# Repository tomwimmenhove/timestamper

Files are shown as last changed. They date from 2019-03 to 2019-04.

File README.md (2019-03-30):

# The Timestamper

This project lets you get get exact timestamps of 'events' (electric pulses on an input).

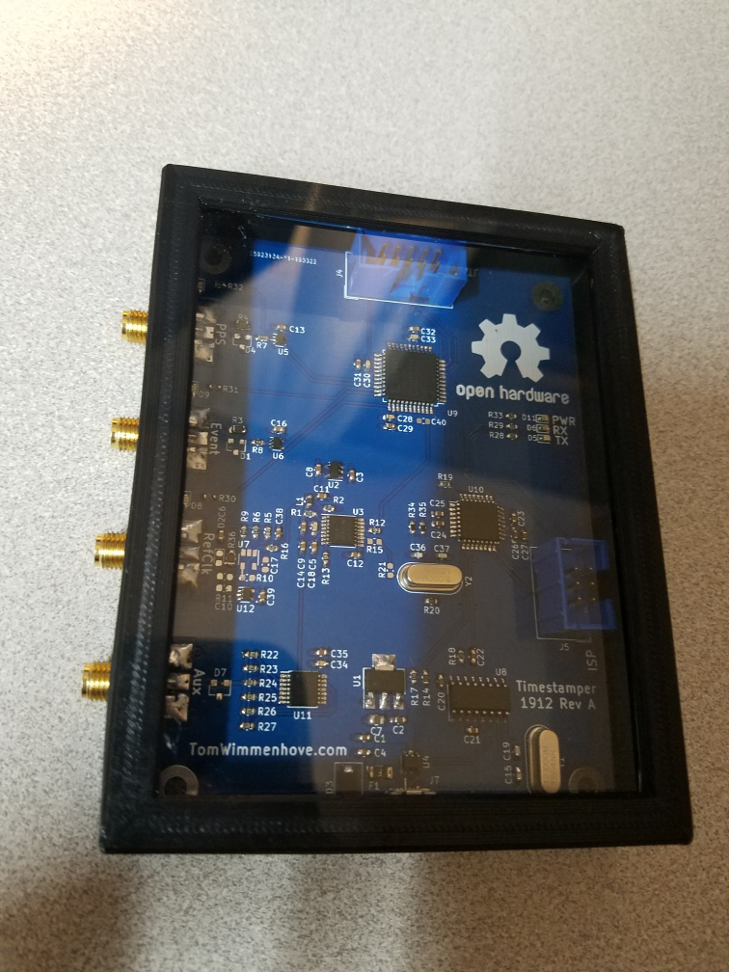
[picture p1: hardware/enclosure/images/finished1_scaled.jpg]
TimeStamper image


## Hardware
The hardware (schematic and PCB) are designed in KiCad 5, and can be found in the ./hardware/cpld/ directory. The 'heart'
of the design is a Xilinx XC9572XL CPLD. This CPLD implements a capture-counter which timestamps the arrival of events
with a resolution of 10ns. This CPLD is programmed in VHDL using Xilinx's ISE 14.7 (https://www.xilinx.com/support/download/index.html/content/xilinx/en/downloadNav/design-tools/v2012_4---14_7.html).

The VHDL project resides in the ./hardware/cpld/ directory. The XC9572XL can be programmed using the xc3sprog (http://xc3sprog.sourceforge.net/) utility.
Both the 'ft232h' (with a serial FT232H UART chip) and the 'sysfsgpio' (sysfsgpio on the Raspberry Pi) have been
successfully used to program the chip.

## Firmware
The firmware runs on an Atmel Atmega328p, which makes it compatible with the arduino. This way, using the default bootloader for,
for example, the Arduino pro mini 3.3v @8Mhz, we can easily program the firmware using avrdude. The firmware simply reads the
captured values from the CPLD and passes them on to a CH340G serial to USB UART. The firmware can be found in ./firmware/atmega328/

## Software
The software just outputs the values from the device onto stdout. See ./software/

# Theory of operation
The board is fed 3 signals:
 - A (very stable) 10MHz reference clock (I.E. from an OCXO or atomic rubidium reference)
 - A precise PPS signal, indicating the start of a UTC second. (I.E. from a GPS timing receiver)
 - An event signal that needs to be precisely timestamped.
 
 The 10Mhz is fed into a PLL (A Texas Instruments CDCE925), and multiplied to 100MHz, which is then fed to the CPLD.
 Inside the CPLD, this clocks a 27-bit counter. This counter is (synchronously) reset on the rising edge of the PPS
 signal. The event signal is sampled at every clock pulse, and when a rising-edge is detected, the current count is stored
 inside into a register and the capture counter is 'disarmed'. The CPLD then notifies the Atmega328P through an interrupt
 which, in turn, reads the value from the CPLD, places it in a buffer, and instructs the CPLD te re-arm the capture logic.
 The capture value is then simply sent out of the USB UART to the PC. We now have the fractional part of the timestamp on
 the PC. This can be combined with the current time on the PC to form a complete timestamp.
 NOTE: This assumes that the time on the PC that is reading the timestamps is well within a 500ms tolerance.
 
 # Links and other stuff
 See https://www.febo.com/pages/soekris/ for details on making an accurate NTP server.
 In addition, a Motorola m12+ GPS timing receiver together with a saw-tooth correction circuit is used to provide both a
 UTC time-source for the NTP server, as well as a PPS pulse for the Timestamper board.
 The Timestamper board also contains an 'auxiliary' output, which could be programmed to output a 33MHz clock that could
 be fed into the Soekris' motherboard to provide an even more accurate NTP time source (untested).

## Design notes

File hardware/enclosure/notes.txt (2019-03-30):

You might want to print the lid at a 99.5% scale.

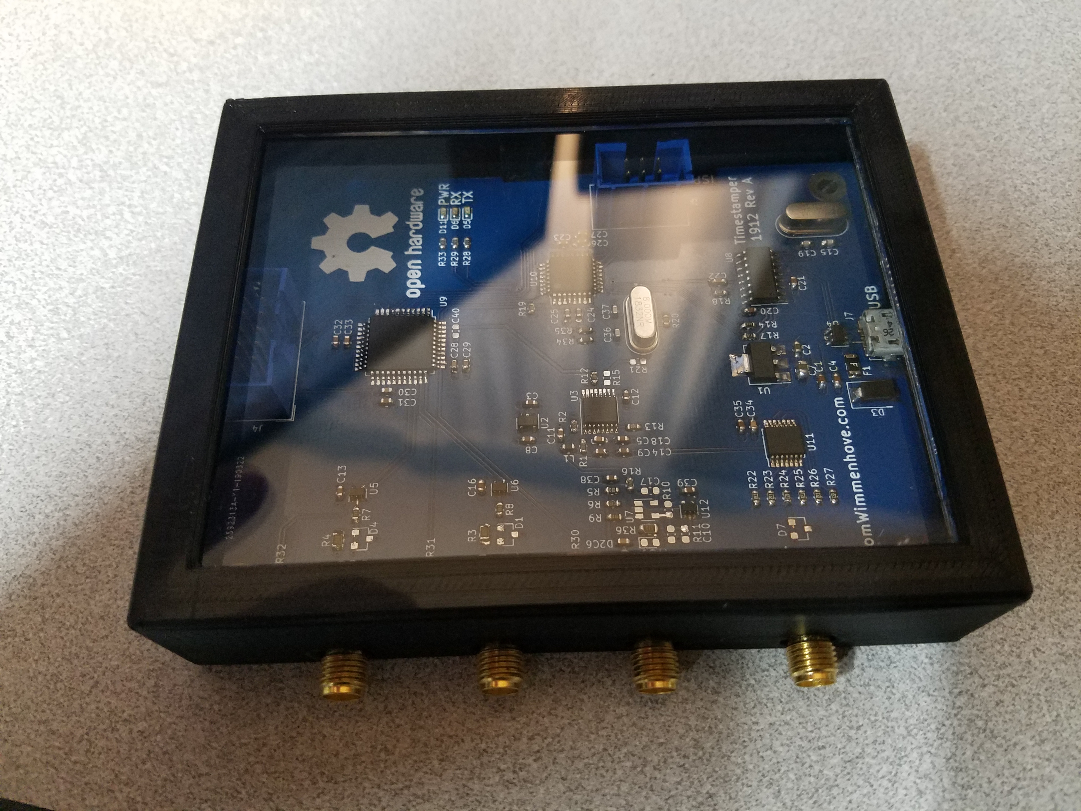
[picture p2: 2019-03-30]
hardware/enclosure/images/finished2.jpg

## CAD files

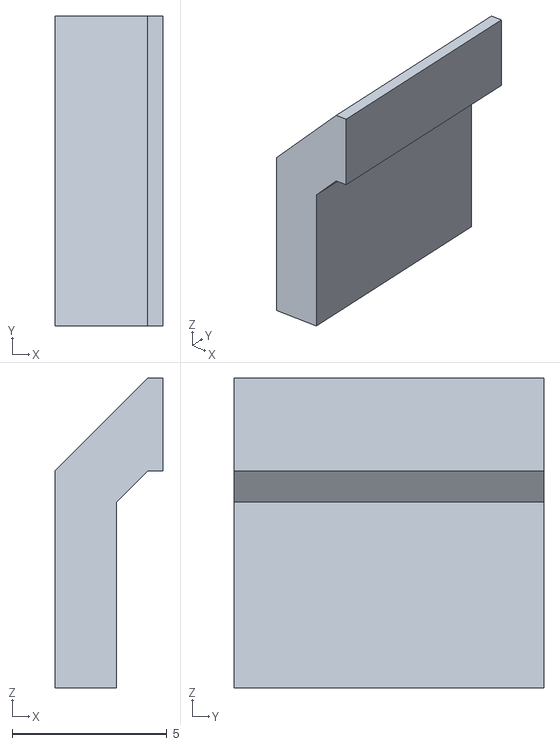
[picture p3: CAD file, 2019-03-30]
hardware/enclosure/pcb_clip.stl
3.50 x 10.0 x 10.0

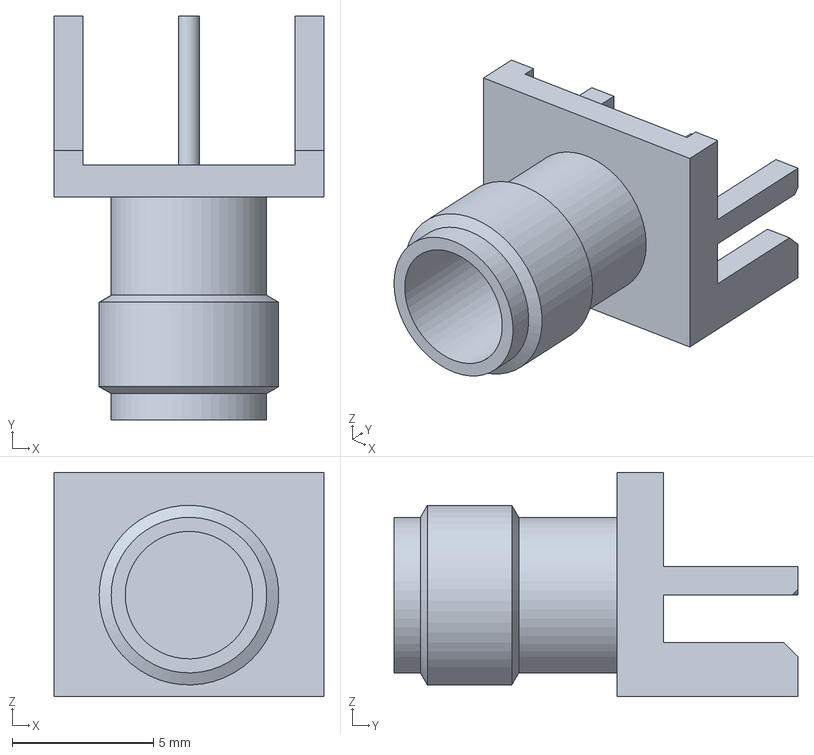
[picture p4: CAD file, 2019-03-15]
hardware/pcb/3dmodels/SMA_Board_Edge_Molex_732511150.step
9.53 x 14.3 x 7.93 mm

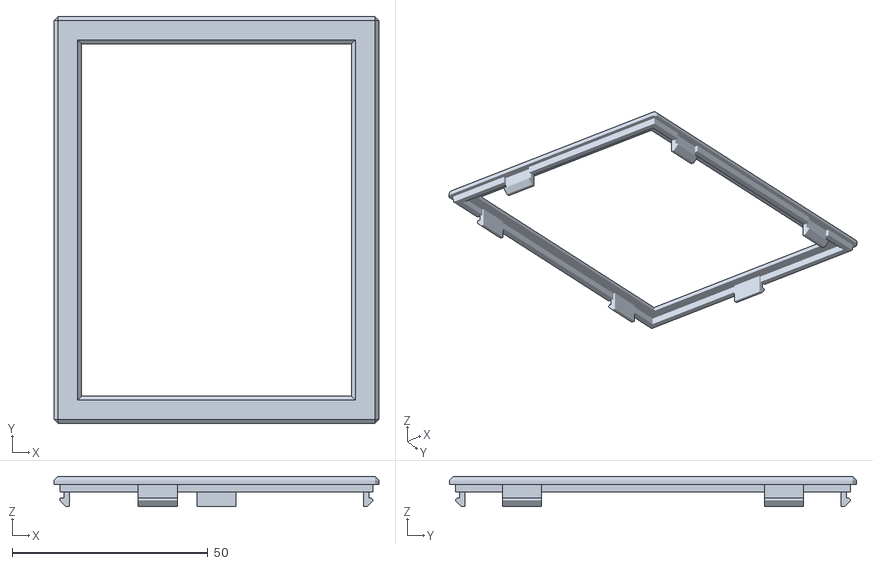
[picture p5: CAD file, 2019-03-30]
hardware/enclosure/lid.stl
83.0 x 104.0 x 7.70

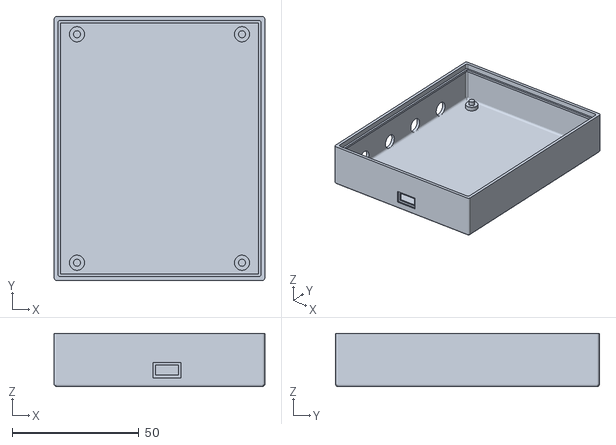
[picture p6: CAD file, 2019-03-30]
hardware/enclosure/bottom.stl
83.0 x 104.0 x 21.0

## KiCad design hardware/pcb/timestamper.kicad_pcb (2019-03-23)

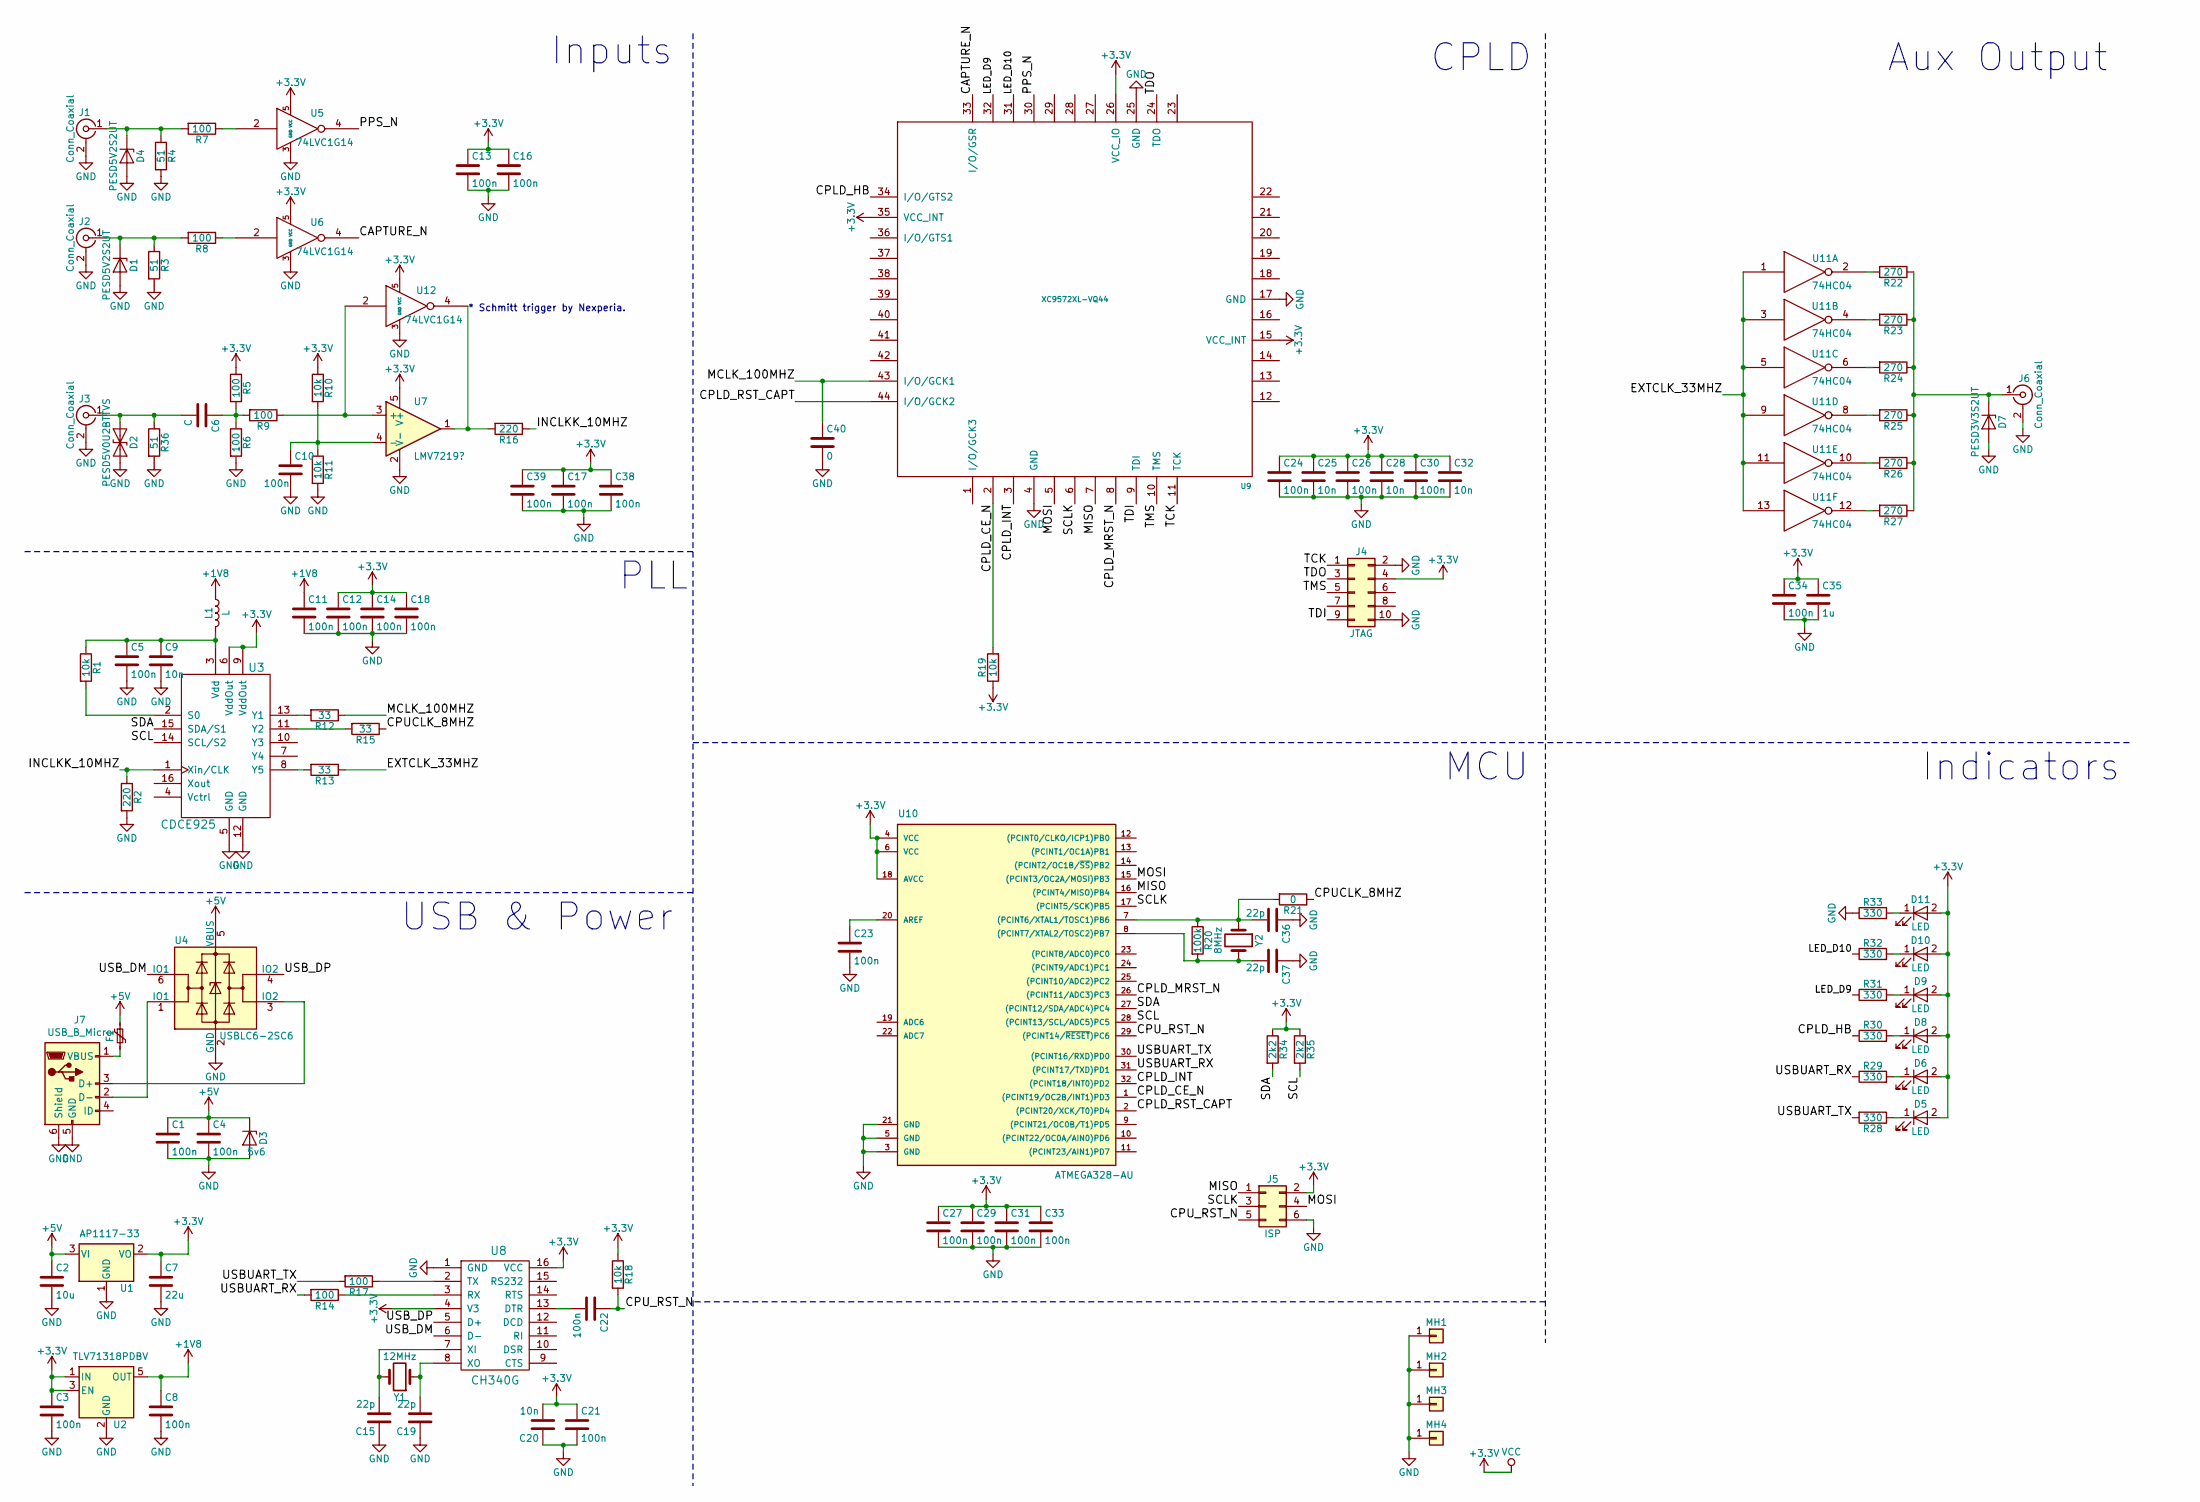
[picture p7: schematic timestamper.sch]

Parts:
C1, C3, C4, C5, C8, C10, C11, C12, C13, C14, C16, C17, C18, C21, C22, C23, C24, C26, C27, C29, C30, C31, C33, C34, C38, C39: 100n; C_0603_1608Metric
C2: 10u; C_0603_1608Metric
C6: C; C_0603_1608Metric
C7: 22u; C_0805_2012Metric
C9, C20, C25, C28, C32: 10n; C_0603_1608Metric
C15, C19, C36, C37: 22p; C_0603_1608Metric
C35: 1u; C_0603_1608Metric
C40: 0; C_0603_1608Metric
D1, D4: PESD5V2S2UT; D_SOT-23_NKA
D2: PESD5V0U2BTTVS; D_0603_1608Metric
D3: 5v6; D_SMB
D5, D6, D8, D9, D10, D11: LED; LED_0603_1608Metric
D7: PESD3V3S2UT; D_SOT-23_NKA
F1: Polyfuse_Small; R_1206_3216Metric
J1, J2, J3, J6: Conn_Coaxial; Molex_SMA_Jack_Edge_Mount
J4: JTAG; IDC-Header_2x05_P2.54mm_Vertical
J5: ISP; IDC-Header_2x03_P2.54mm_Vertical
J7: USB_B_Micro; USB_Micro-B_Molex_47346-0001
L1: L; L_0603_1608Metric
MH1, MH2, MH3, MH4: Conn_01x01; MountingHole_3.2mm_M3_Pad
R1, R10, R11, R18, R19: 10k; R_0603_1608Metric
R2, R16: 220; R_0603_1608Metric
R3, R4, R36: 51; R_0805_2012Metric
R5, R6, R7, R8, R9, R14, R17: 100; R_0603_1608Metric
R12, R13, R15: 33; R_0603_1608Metric
R20: 100k; R_0603_1608Metric
R21: 0; R_0603_1608Metric
R22, R23, R24, R25, R26, R27: 270; R_0603_1608Metric
R28, R29, R30, R31, R32, R33: 330; R_0603_1608Metric
R34, R35: 2k2; R_0603_1608Metric
U1: AP1117-33; SOT-223-3_TabPin2
U2: TLV71318PDBV; SOT-23-5
U3: CDCE925; TSSOP-16_4.4x5mm_P0.65mm
U4: USBLC6-2SC6; SOT-23-6
U5, U6, U12: 74LVC1G14; SOT-353_SC-70-5
U7: LMV7219?; SOT-23-5
U8: CH340G; SOIC-16_3.9x9.9mm_P1.27mm
U9: XC9572XL-VQ44; PQFP-44_10x10mm_P0.8mm
U10: ATMEGA328-AU; TQFP-32_7x7mm_P0.8mm
U11: 74HC04; TSSOP-14_4.4x5mm_P0.65mm
Y1: 12MHz; Crystal_HC49-4H_Vertical
Y2: 8MHz; Crystal_HC49-4H_Vertical

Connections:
+1V8: C8.1, C11.1, L1.1, U2.5 (OUT)
+3V3: C3.1, C7.1, C12.1, C13.1, C14.1, C16.1, C17.1, C18.1, C20.2, C21.1, C24.1, C25.1, C26.1, C27.1, C28.1, C29.1, C30.1, C31.1, C32.1, C33.1, C34.1, C35.1, C38.1, C39.1, D5.2 (A), D6.2 (A), D8.2 (A), D9.2 (A), D10.2 (A), D11.2 (A), J4.4, J5.2, R5.1, R10.1, R18.1, R19.1, R34.1, R35.1, U1.2 (VO), U2.1 (IN), U2.3 (EN), U3.6 (VddOut), U3.9 (VddOut), U5.5 (VCC), U6.5 (VCC), U7.5 (V+), U8.4 (V3), U8.16 (VCC), U9.15 (VCC_INT), U9.26 (VCC_IO), U9.35 (VCC_INT), U10.4 (VCC), U10.6 (VCC), U10.18 (AVCC), U11.14 (VCC), U12.5 (VCC)
+5V: C1.1, C2.1, C4.1, D3.1 (K), F1.1, U1.3 (VI), U4.5 (VBUS)
/CAPTURE_N: U6.4, U9.33 (I/O/GSR)
/CPLD_CE_N: R19.2, U9.2, U10.1 ((PCINT19/OC2B/INT1)PD3)
/CPLD_HB: R30.1, U9.34 (I/O/GTS2)
/CPLD_INT: U9.3, U10.32 ((PCINT18/INT0)PD2)
/CPLD_MRST_N: U9.8, U10.26 ((PCINT11/ADC3)PC3)
/CPLD_RST_CAPT: U9.44 (I/O/GCK2), U10.2 ((PCINT20/XCK/T0)PD4)
/CPUCLK_8MHZ: R15.1, R21.1
/CPU_RST_N: C22.1, J5.5, R18.2, U10.29 ((PCINT14/~RESET~)PC6)
/EXTCLK_33MHZ: R13.1, U11.1, U11.3, U11.5, U11.9, U11.11, U11.13
/INCLKK_10MHZ: R2.1, R16.1, U3.1 (Xin/CLK)
/LED_D9: R31.1, U9.32
/LED_D10: R32.1, U9.31
/MCLK_100MHZ: C40.1, R12.1, U9.43 (I/O/GCK1)
/MISO: J5.1, U9.7, U10.16 ((PCINT4/MISO)PB4)
/MOSI: J5.4, U9.5, U10.15 ((PCINT3/OC2A/MOSI)PB3)
/PPS_N: U5.4, U9.30
/SCL: R35.2, U3.14 (SCL/S2), U10.28 ((PCINT13/SCL/ADC5)PC5)
/SCLK: J5.3, U9.6, U10.17 ((PCINT5/SCK)PB5)
/SDA: R34.2, U3.15 (SDA/S1), U10.27 ((PCINT12/SDA/ADC4)PC4)
/TCK: J4.1, U9.11 (TCK)
/TDI: J4.9, U9.9 (TDI)
/TDO: J4.3, U9.24 (TDO)
/TMS: J4.5, U9.10 (TMS)
/USBUART_RX: R14.2, R29.1, U10.31 ((PCINT17/TXD)PD1)
/USBUART_TX: R17.2, R28.2, U10.30 ((PCINT16/RXD)PD0)
/USB_DM: U4.6 (IO1), U8.6 (D-)
/USB_DP: U4.4 (IO2), U8.5 (D+)
GND: C1.2, C2.2, C3.2, C4.2, C5.2, C7.2, C8.2, C9.2, C10.2, C11.2, C12.2, C13.2, C14.2, C15.1, C16.2, C17.2, C18.2, C19.1, C20.1, C21.2, C23.2, C24.2, C25.2, C26.2, C27.2, C28.2, C29.2, C30.2, C31.2, C32.2, C33.2, C34.2, C35.2, C36.1, C37.1, C38.2, C39.2, C40.2, D1.2 (A), D2.2 (A2), D3.2 (A), D4.2 (A), D7.2 (A), J1.2 (Ext), J2.2 (Ext), J3.2 (Ext), J4.2, J4.10, J5.6, J6.2 (Ext), J7.5 (GND), J7.6 (Shield), MH1.1, MH2.1, MH3.1, MH4.1, R2.2, R3.2, R4.2, R6.2, R11.2, R33.1, R36.2, U1.1 (GND), U2.2 (GND), U3.5 (GND), U3.12 (GND), U4.2 (GND), U5.3 (GND), U6.3 (GND), U7.2 (V-), U8.1 (GND), U9.4 (GND), U9.17 (GND), U9.25 (GND), U10.3 (GND), U10.5 (GND), U10.21 (GND), U11.7 (GND), U12.3 (GND)
unnamed: C5.1, C9.1, L1.2, R1.1, U3.3 (Vdd)
unnamed: C6.1, R5.2, R6.1, R9.2
unnamed: C6.2, D2.1 (A1), J3.1 (In), R36.1
unnamed: C10.1, R10.2, R11.1, U7.4 (-)
unnamed: C15.2, U8.7 (XI), Y1.2
unnamed: C19.2, U8.8 (XO), Y1.1
unnamed: C22.2, U8.13 (DTR)
unnamed: C23.1, U10.20 (AREF)
unnamed: C36.2, R20.1, R21.2, U10.7 ((PCINT6/XTAL1/TOSC1)PB6), Y2.1
unnamed: C37.2, R20.2, U10.8 ((PCINT7/XTAL2/TOSC2)PB7), Y2.2
unnamed: D1.1 (K), J2.1 (In), R3.1, R8.2
unnamed: D4.1 (K), J1.1 (In), R4.1, R7.2
unnamed: D5.1 (K), R28.1
unnamed: D6.1 (K), R29.2
unnamed: D7.1 (K), J6.1 (In), R22.1, R23.1, R24.1, R25.1, R26.1, R27.1
unnamed: D8.1 (K), R30.2
unnamed: D9.1 (K), R31.2
unnamed: D10.1 (K), R32.2
unnamed: D11.1 (K), R33.2
unnamed: F1.2, J7.1 (VBUS)
unnamed: J7.2 (D-), U4.1 (IO1)
unnamed: J7.3 (D+), U4.3 (IO2)
unnamed: R1.2, U3.2 (S0)
unnamed: R7.1, U5.2
unnamed: R8.1, U6.2
unnamed: R9.1, U7.3 (+), U12.2
unnamed: R12.2, U3.13 (Y1)
unnamed: R13.2, U3.8 (Y5)
unnamed: R14.1, U8.3 (RX)
unnamed: R15.2, U3.11 (Y2)
unnamed: R16.2, U7.1, U12.4
unnamed: R17.1, U8.2 (TX)
unnamed: R22.2, U11.2
unnamed: R23.2, U11.4
unnamed: R24.2, U11.6
unnamed: R25.2, U11.8
unnamed: R26.2, U11.10
unnamed: R27.2, U11.12

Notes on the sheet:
Indicators
Aux Output
CPLD
MCU
Inputs
PLL
USB & Power
* Schmitt trigger by Nexperia.

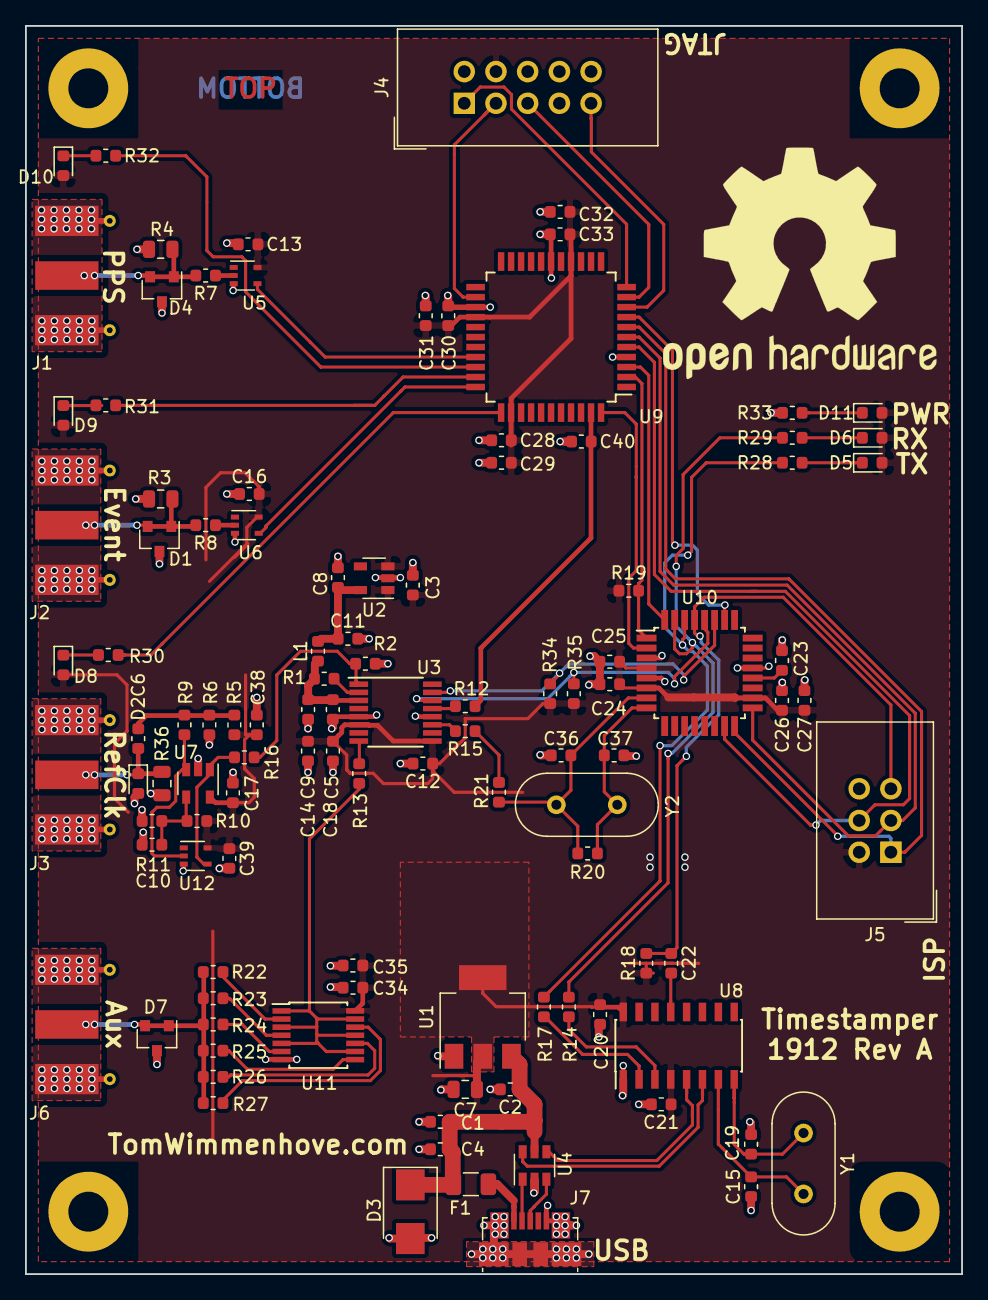
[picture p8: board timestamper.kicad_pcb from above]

Board: 2 copper layers, 75.0 x 100.0 mm, 114 parts (0 on the bottom side), 69 nets.

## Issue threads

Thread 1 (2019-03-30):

TX and RX label swapped on PCB

tomwimmenhove, 2019-03-30:

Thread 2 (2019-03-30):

SMA connector footprints are wrong

tomwimmenhove, 2019-03-30:
The SMA connector (ground) pins are too far apart.

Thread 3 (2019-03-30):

Wrong ESD protection diodes

tomwimmenhove, 2019-03-30:
The PESD* ESD protection devices have way too high a capacitance.

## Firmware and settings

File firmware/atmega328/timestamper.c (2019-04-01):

/* 
 * This file is part of the TimeStamper distribution (https://github.com/tomwimmenhove/timestamper)
 * Copyright (c) 2019 Tom wimmenhove
 * 
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
 * You should have received a copy of the GNU General Public License 
 * along with this program. If not, see <http://www.gnu.org/licenses/>.
 */

#include <avr/io.h>
#include <avr/interrupt.h>
#include <stdio.h>
#include <util/twi.h>
#include <string.h>
#include <util/delay.h>

#include "ttys.h"
#include "i2c_master.h"
#include "spi.h"
#include "circ_buf.h"
#include "pindefs.h"
#include "cdce925.h"

/* For lower baud-rates use a circular buffer to be able
 * to deal with capture pulses in quick succession.
 * For high baud rates it's probably more effective to
 * send the data as it comes in. 
 * More testing should be done here!
 */
#define USE_CIRC_BUF

#ifdef USE_CIRC_BUF
#define BUFSIZE 32 // Power of two
#endif

/* Set the UART's baud-rate for the */
/* XXX: Apparently the CH340G's error rate if fucking _horrid_
 * at high bit-rates. 38400 seems to be the only safe limit that
 * we can use on an 8MHz controller :( */
//#define BAUD 500000
//#define BAUD 57600
//#define BAUD 9600
//#define BAUD 38400
#define BAUD 76800

void setup_hw()
{
	/* Setup UART */
#include <util/setbaud.h>
	UBRR0H = UBRRH_VALUE;
	UBRR0L = UBRRL_VALUE;
	UCSR0C = _BV(UCSZ01) | _BV(UCSZ00);
	UCSR0B = _BV(RXEN0) | _BV(TXEN0);
#if USE_2X
	UCSR0A |= (1 << U2X0);
#else
	UCSR0A &= ~(1 << U2X0);
#endif

	printf_init();
//	printf("Initializing...");

	/* Initialize I2C */
	i2c_init();

	/* Configure output pins */
	SCLK_DDR |= SCLK_MASK;
	SS_DDR |= SS_MASK;
	MR_DDR |= MR_MASK;
	CS_DDR |= CS_MASK;
	RESET_CAPT_DDR |= RESET_CAPT_MASK;

	/* Setup SPI */
	SS_PORT |= SS_MASK; // SS Always high. Low would cause us to go into slave-mode.
	SPCR |= _BV(MSTR);
	SPCR |= _BV(SPE);

	/* CS high */
	CS_PORT |= CS_MASK;

	/*Reset the CPLD */
	MR_PORT &= ~MR_MASK;
	MR_PORT |= MR_MASK;

	/* Wait at least a second before we start capturing, in order to make sure 
	 * we've captured a PPS pulse */
	for (int i = 0; i < 100; i++)
		_delay_ms(10);

	/* Re-set capture in case a capture event happened while we were waiting. */
	RESET_CAPT_PORT |= RESET_CAPT_MASK;
	RESET_CAPT_PORT &= ~RESET_CAPT_MASK;

	/* Setup interrupts */
	MCUCR = 0;  // Trigger INT0 on low level
	EIMSK = 1;
//	sei();		// Enable

//	printf("OK\r\n");
}

#ifdef USE_CIRC_BUF
static volatile uint32_t capture_buffer[BUFSIZE];
static volatile int8_t tail = 0;
static volatile int8_t head = 0;
#endif

static inline void packet_out(uint32_t x)
{
	uart_putchar(((x >> 21) & 0x7f) | 0x80);
	uart_putchar( (x >> 14) & 0x7f);
	uart_putchar( (x >>  7) & 0x7f);
	uart_putchar(  x        & 0x7f);
}

ISR(INT0_vect)
{
#ifdef USE_CIRC_BUF
	if(!CIRC_SPACE(head, tail, BUFSIZE))
	{
		EIMSK = 0;  // Waaaait for it...
		return;
	}
#endif

	/* Read the capture register */
	CS_PORT &= ~CS_MASK;
	uint8_t a = spi_inout(0x00);
	uint8_t b = spi_inout(0x00);
	uint8_t c = spi_inout(0x00);
	uint8_t d = spi_inout(0x00);
	CS_PORT |= CS_MASK;

	/* Re-enable capture */
	RESET_CAPT_PORT |= RESET_CAPT_MASK;
	RESET_CAPT_PORT &= ~RESET_CAPT_MASK;

	uint32_t data = (uint32_t) a << 24 | (uint32_t) b << 16 | (uint32_t) c << 8 | (uint32_t) d;

#ifdef USE_CIRC_BUF
	capture_buffer[head] = data;
	head = (head + 1) % BUFSIZE;
#else
	packet_out(data);
#endif
}

static inline uint32_t unpack(uint8_t* data)
{
	return (((uint32_t) data[0] & 0x7f) << 21) | ((uint32_t) data[1] << 14) | ((uint32_t) data[2] << 7) | (uint32_t) data[3];
}

void handle_event(uint32_t cmd)
{
	switch((cmd >> 16) & 0xff)
	{
		case 0x01:
			{
			sei();
			tail = head = 0;
			packet_out(cmd); // ACK
			break;
			}
		case 0x02:
			{
			cli();
			packet_out(cmd); // ACK
			tail = head = 0;
			break;
			}

		case 0x03: // read cdce925 reg
			{
			uint8_t r = read_cdce925_reg((cmd & 0xff) | 0x80);
			cmd &= ~0xff;
			cmd |= r;

			packet_out(cmd); // ACK, result
			return;
			}
		case 0x04: // write cdce925 reg
			{
			write_cdce925_reg((cmd & 0xff) | 0x80, cmd >> 8);
			packet_out(cmd); // ACK
			break;
			}

		case 0x05: // Write initial values to cdce925
			cdce925_init();
			packet_out(cmd); // ACK
			break;

		case 0x06: // Write PLL config to PLL's EEPROM
			cdce925_burn();
			packet_out(cmd); // ACK
			break;
	}
}

void main()
{
	uint8_t packet[4];
	int pos = 0;

	setup_hw();

	packet_out(0x08000000); // I'm ready...

	while (1)
	{
#ifdef USE_CIRC_BUF
		while (CIRC_CNT(head, tail, BUFSIZE))
		{
			uint32_t data = capture_buffer[tail];
			tail = (tail + 1) % BUFSIZE;

//			printf("%ld\r\n", data);
			packet_out(data);

			EIMSK = 1; // re-enable interrupts (in case they were disabled, in the event of a full buffer)
		}
#endif

		if (uart_haschar())
		{
			uint8_t b = uart_getchar();

			/* Start of 'packet' */
			if (b & 0x80)
			{   
				pos = 0;
			}
			if (pos < 4)
			{   
				packet[pos] = b;
			}

			pos++;

			if (pos == 4)
			{
				uint32_t x = unpack(packet);

				handle_event(x);
			}
		}
	}
}

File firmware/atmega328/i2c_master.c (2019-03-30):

// This file is largely based on https://github.com/g4lvanix/I2C-master-lib

#include <avr/io.h>
#include <util/twi.h>

#include "i2c_master.h"

#define F_SCL 100000UL // SCL frequency
#define Prescaler 1
#define TWBR_val ((((F_CPU / F_SCL) / Prescaler) - 16 ) / 2)

void i2c_init(void)
{
	TWBR = (uint8_t)TWBR_val;
}

uint8_t i2c_start(uint8_t address)
{
	// reset TWI control register
	TWCR = 0;
	// transmit START condition 
	TWCR = (1<<TWINT) | (1<<TWSTA) | (1<<TWEN);
	// wait for end of transmission
	while( !(TWCR & (1<<TWINT)) );
	
	// check if the start condition was successfully transmitted
	if((TWSR & 0xF8) != TW_START){ return 1; }
	
	// load slave address into data register
	TWDR = address;
	// start transmission of address
	TWCR = (1<<TWINT) | (1<<TWEN);
	// wait for end of transmission
	while( !(TWCR & (1<<TWINT)) );
	
	// check if the device has acknowledged the READ / WRITE mode
	uint8_t twst = TW_STATUS & 0xF8;
	if ( (twst != TW_MT_SLA_ACK) && (twst != TW_MR_SLA_ACK) ) return 1;
	
	return 0;
}

uint8_t i2c_write(uint8_t data)
{
	// load data into data register
	TWDR = data;
	// start transmission of data
	TWCR = (1<<TWINT) | (1<<TWEN);
	// wait for end of transmission
	while( !(TWCR & (1<<TWINT)) );
	
	if( (TWSR & 0xF8) != TW_MT_DATA_ACK ){ return 1; }
	
	return 0;
}

uint8_t i2c_read_ack(void)
{
	
	// start TWI module and acknowledge data after reception
	TWCR = (1<<TWINT) | (1<<TWEN) | (1<<TWEA); 
	// wait for end of transmission
	while( !(TWCR & (1<<TWINT)) );
	// return received data from TWDR
	return TWDR;
}

uint8_t i2c_read_nack(void)
{
	
	// start receiving without acknowledging reception
	TWCR = (1<<TWINT) | (1<<TWEN);
	// wait for end of transmission
	while( !(TWCR & (1<<TWINT)) );
	// return received data from TWDR
	return TWDR;
}

uint8_t i2c_transmit(uint8_t address, uint8_t* data, uint16_t length)
{
	if (i2c_start(address | I2C_WRITE)) return 1;
	
	for (uint16_t i = 0; i < length; i++)
	{
		if (i2c_write(data[i])) return 1;
	}
	
	i2c_stop();
	
	return 0;
}

uint8_t i2c_receive(uint8_t address, uint8_t* data, uint16_t length)
{
	if (i2c_start(address | I2C_READ)) return 1;
	
	for (uint16_t i = 0; i < (length-1); i++)
	{
		data[i] = i2c_read_ack();
	}
	data[(length-1)] = i2c_read_nack();
	
	i2c_stop();
	
	return 0;
}

uint8_t i2c_writeReg(uint8_t devaddr, uint8_t regaddr, uint8_t* data, uint16_t length)
{
	if (i2c_start(devaddr | 0x00)) return 1;

	i2c_write(regaddr);

	for (uint16_t i = 0; i < length; i++)
	{
		if (i2c_write(data[i])) return 1;
	}

	i2c_stop();

	return 0;
}

uint8_t i2c_readReg(uint8_t devaddr, uint8_t regaddr, uint8_t* data, uint16_t length)
{
	if (i2c_start(devaddr)) return 1;

	i2c_write(regaddr);

	if (i2c_start(devaddr | 0x01)) return 1;

	for (uint16_t i = 0; i < (length-1); i++)
	{
		data[i] = i2c_read_ack();
	}
	data[(length-1)] = i2c_read_nack();

	i2c_stop();

	return 0;
}

void i2c_stop(void)
{
	// transmit STOP condition
	TWCR = (1<<TWINT) | (1<<TWEN) | (1<<TWSTO);
}

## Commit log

2019-03-02 Converted to lower case
2019-03-12 Added KiCad pcb project
    [_saved_timestamper.sch, timestamper.kicad_pcb, timestamper.sch]
2019-03-12 Added arduino/atmel firmware
2019-03-12 Fixed after relocating KiCad project
    [_saved_timestamper.sch, timestamper.sch]
2019-03-13 Initial component placement
    [timestamper.kicad_pcb, timestamper.sch]
2019-03-13 Upgraded to KiCad 5.0
    [_saved_timestamper.sch, timestamper-2019-03-13-11-08-10.sch]
2019-03-13 Changed some libraries
    [_saved_timestamper.sch, timestamper.sch]
2019-03-14 Updated R and C footprints
    [timestamper.kicad_pcb, timestamper.sch]
2019-03-14 Updated all footprints
    [timestamper.kicad_pcb, timestamper.sch]
2019-03-14 Finished most of routing
    [timestamper.kicad_pcb, timestamper.sch]
2019-03-15 Synched pinouts between CPLD and PCB
    [timestamper.kicad_pcb, timestamper.sch]
2019-03-15 Moved refdesses, added silk-screen anotations
    [timestamper.kicad_pcb]
2019-03-15 Forgot to change L1 footprint
    [timestamper.kicad_pcb, timestamper.sch]
2019-03-15 Added SMA 3d model
    [SMA_Board_Edge_Molex_732511150.step, timestamper.kicad_pcb]
2019-03-15 Added silk-screen comments
    [timestamper.kicad_pcb]
2019-03-15 Minor schematic cleanup
    [timestamper.sch]
2019-03-15 Fixed CH340G (U8) foot print
    [timestamper.kicad_pcb, timestamper.sch]
2019-03-16 Added optional schmitt input on refclk
    [timestamper.kicad_pcb, timestamper.sch]
2019-03-17 Ground via insanity reduction
    [timestamper.kicad_pcb]
2019-03-17 VCC plane on top
    [timestamper.kicad_pcb]
2019-03-17 Small fixes
    [timestamper.kicad_pcb, timestamper.sch]
2019-03-18 Fixed mask clearance. Keep-out around mounting holes
    [timestamper.kicad_pcb]
2019-03-20 Replaced arduino with native avr project
    [i2c_master.c, timestamper.c]
2019-03-20 Made interrupt line active low
2019-03-21 Some more cleaning up
    [timestamper.kicad_pcb]
2019-03-21 Final changes before first board spin
    [timestamper.kicad_pcb]
2019-03-23 Added uart_puts() for testing
2019-03-23 Added simple udev rule for consistent (with a single CH340) device naming
2019-03-28 Working with first board spin!
2019-03-30 Added 3D printable enclosure
    [bottom.stl, lid.stl, pcb_clip.stl]
2019-03-30 Configurable PLL frequency. Fixes #4
    [timestamper.c]
2019-03-30 Avoid interrupts when buffer is full
    [timestamper.c]
2019-03-31 Temporary hacky fix for stupid serial comm bug
    [timestamper.c]
2019-04-01 Negative error printing bug
    [timestamper.c]

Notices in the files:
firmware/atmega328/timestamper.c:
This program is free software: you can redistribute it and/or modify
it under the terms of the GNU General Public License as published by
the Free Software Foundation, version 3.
